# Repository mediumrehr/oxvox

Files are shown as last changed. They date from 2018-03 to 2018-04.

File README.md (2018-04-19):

# Ox Vox

The Ox Vox is a badge add-on created for the DEF CON 25 503 party and BSides PDX 2018 badges. The Ox Vox replaces the two joysticks on the badge with eight buttons and amplified speaker output.

## How To

### Connecting

Connecting the Ox Vox requires removing the joysticks from the badge. The pinouts are different for the DC25 Badge vs the BSides badge, so a few defines need to be changed depending on which badge you are modifying. Each joysticks uses five GPIOs, which allows for eight button inputs (a full octave), audio out, and an amplifier enable (see [Addition](#additions)).

Below shows how to connect the Ox Vox depending on which badge you're modifying.

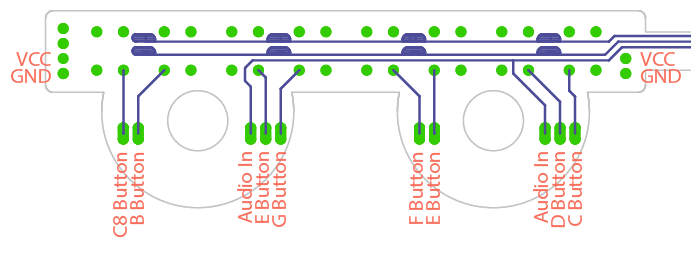
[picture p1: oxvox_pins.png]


#### DEF CON 25 503 Party Badge

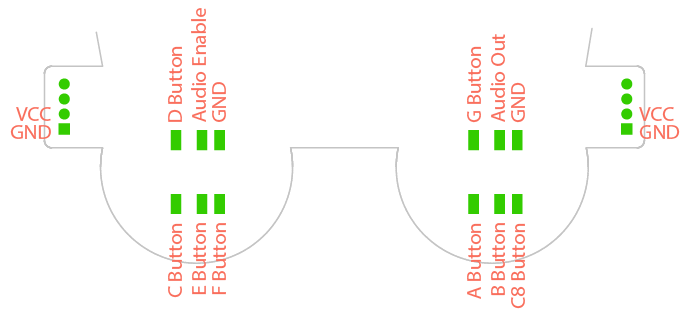
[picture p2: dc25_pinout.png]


#### BSides PDX Badge

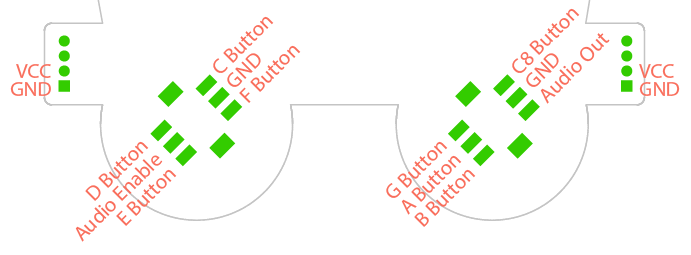
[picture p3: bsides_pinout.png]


### Programming

There are a few methods for programming the BMD-300 (NRF52832) SoC with the Ox Vox firmware via SWD. For this this project, I've been using the [BMD-300 Eval Kit](https://www.digikey.com/product-detail/en/rigado-inc/BMD-300-EVAL/1604-1007-ND/5958042) as a Segger J-Link Debugger as outlined in [this article](https://rigado.zendesk.com/hc/en-us/articles/223486428-How-are-the-BMD-200-and-BMD-300-Series-modules-programmed-). There are many cheap (<$10) J-Link-OB devices available that will likely work just as well, or you can probably use any other SWD device you have laying around.

In order to program the board, you need to break out the SWD interface. This requires soldering four male header pins to the pads shown below (directly below the i2c screen header). Looking at the badge from the back, the pins are SWCLK, SWDIO, 3v3, and GND.

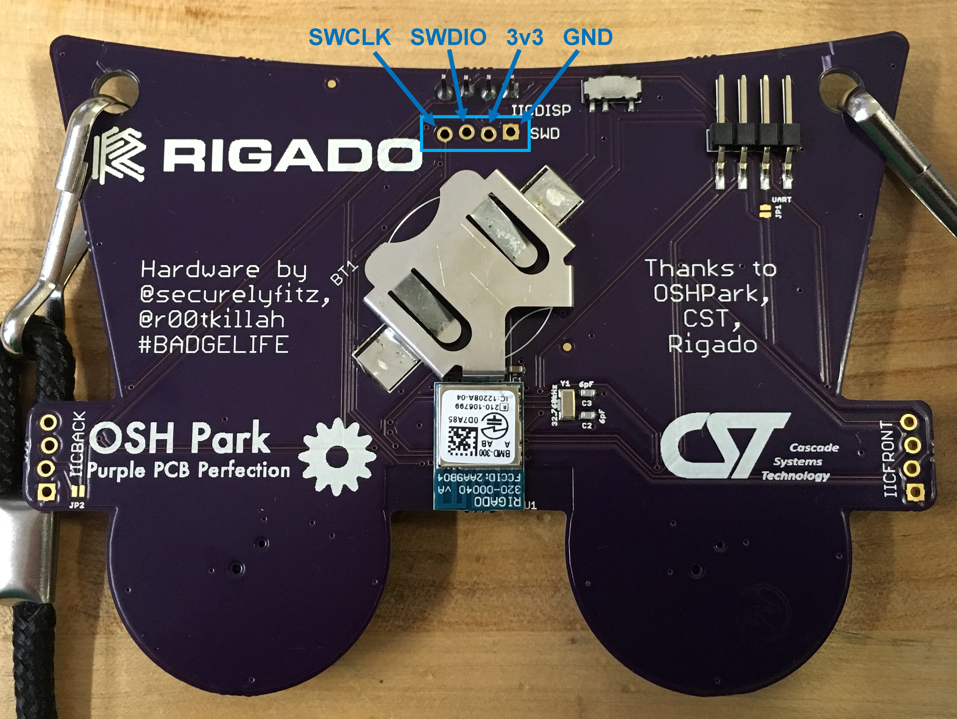
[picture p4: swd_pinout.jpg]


If you're using a J-Link interface, the badge should show mount to your OS when you plug it into your computer. You can then drop the appropriate (DC25 vs BSides) compiled hex file into the mounted folder and the NRF52 will take it from there.

If you want to build from source, follow [this guide](https://www.rigado.com/bmd-300-series-getting-started-guide/?wpdmdl=1810) (starting on page 9) for setting up Keil uVision, the nRF5 SDK, and Segger J-Link. Instead of downloading nRF5 SDK v12, download [nRF5 SDK v13.0.0](https://developer.nordicsemi.com/nRF5_SDK/nRF5_SDK_v13.x.x/) (it's possible this code will work with newer SDKs, but I have not tested with them).

## Hardware

PCB files, designed in Eagle v7.7.0, are included in the Hardware folder. The design features eight momentary-push buttons, a basic smoothing and amplifier circuit, and a .8W speaker. The buttons form a full octave keyboard from C (261.6 Hz) to C (523.3 Hz). The BMD-300 outputs a PWM signal that is smoothed and amplified by the LM4861 amplifier.

## Firmware

To build the project, drop the oxvox foldering into examples->peripheral in the SDK and drop components into the root of the SDK (it fixes a bug in the bsp driver and adds the board definitions to the boards folder). Opening oxvox.uvprojx will open the project in uVision. From there you can build and load the hex file onto the board (either by grabbing the hex file in \_build/ and dropping it onto the mounted JLINK device or by using uVision's load feature). If you're using uVision to load the firmware, make sure it is configured to support whatever SWD programmer you are using; you can configure this under Project->Options for Target->Debug.

## Additions

The Ox Vox amplifier, in combination with the OLED display, were quickly draining fresh batteries, so as proposed by [Scanlime](https://twitter.com/scanlime), I added support in the firmware to connect the shutown pin of the LM4861 to pin xxx of the BMD-300. This allows the amplifier to be turned off when no audio is being played in order to save some power, and so it doesn't compete with the current draw when the display is drawing more white pixels in the default image. In order to do this, the shutdown lead (highlighted below) needs to be desoldered and lifted off the pad, then wired to the xxx pad on the Badge. The shutdown pin was originally connected to ground so the amplifier would remain on, therefore part of the trace is under the LM4861. The easiest way to break that connection is to lift the lead instead of disconnect the pad.

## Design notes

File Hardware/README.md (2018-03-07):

### OX VOX Hardware
Schematic and layout created using [Eagle 7.7.0](https://www.autodesk.com/products/eagle/overview)

The design features eight momentary-push buttons, a basic smoothing and amplifier circuit, and a 800mW speaker. The buttons form a full octave keyboard from C (261.6 Hz) to C (523.3 Hz). The BMD-300 outputs a PWM signal that is smoothed and amplified by the LM4861 amplifier.

This layout is slightly different from the DC25 and BSidesPDX layouts. It features the LM4861 shutdown pin broken out, as suggested by [Micah Scott](https://github.com/scanlime). By breaking out the shutdown pin and connecting it to the remaining available BMD-300 GPIO, the amplifier can be to shutdown when not in use in order to save power. Please see the connection section for how to connect this, or connect it to ground to keep the amplifier always on.

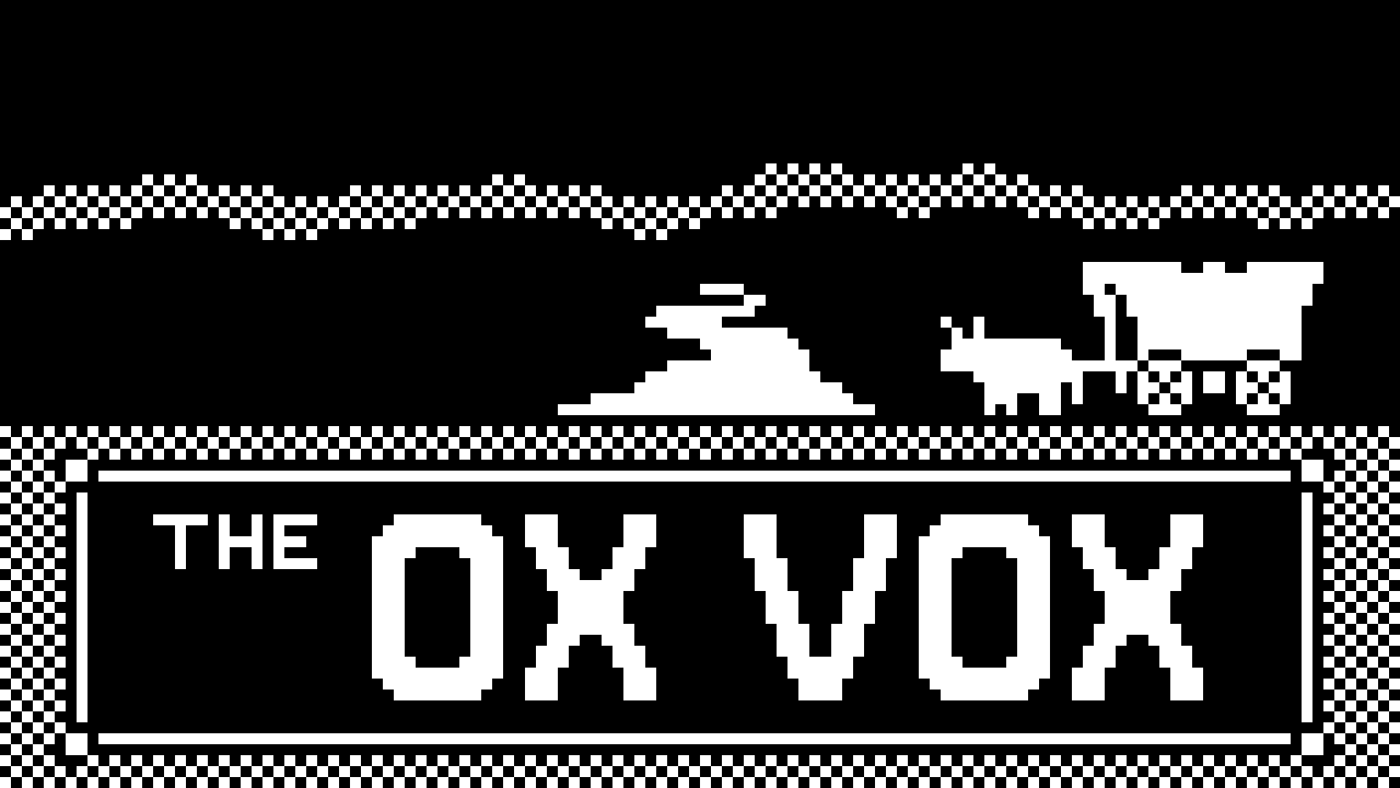
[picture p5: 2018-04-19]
Extras/oxvox_large.png

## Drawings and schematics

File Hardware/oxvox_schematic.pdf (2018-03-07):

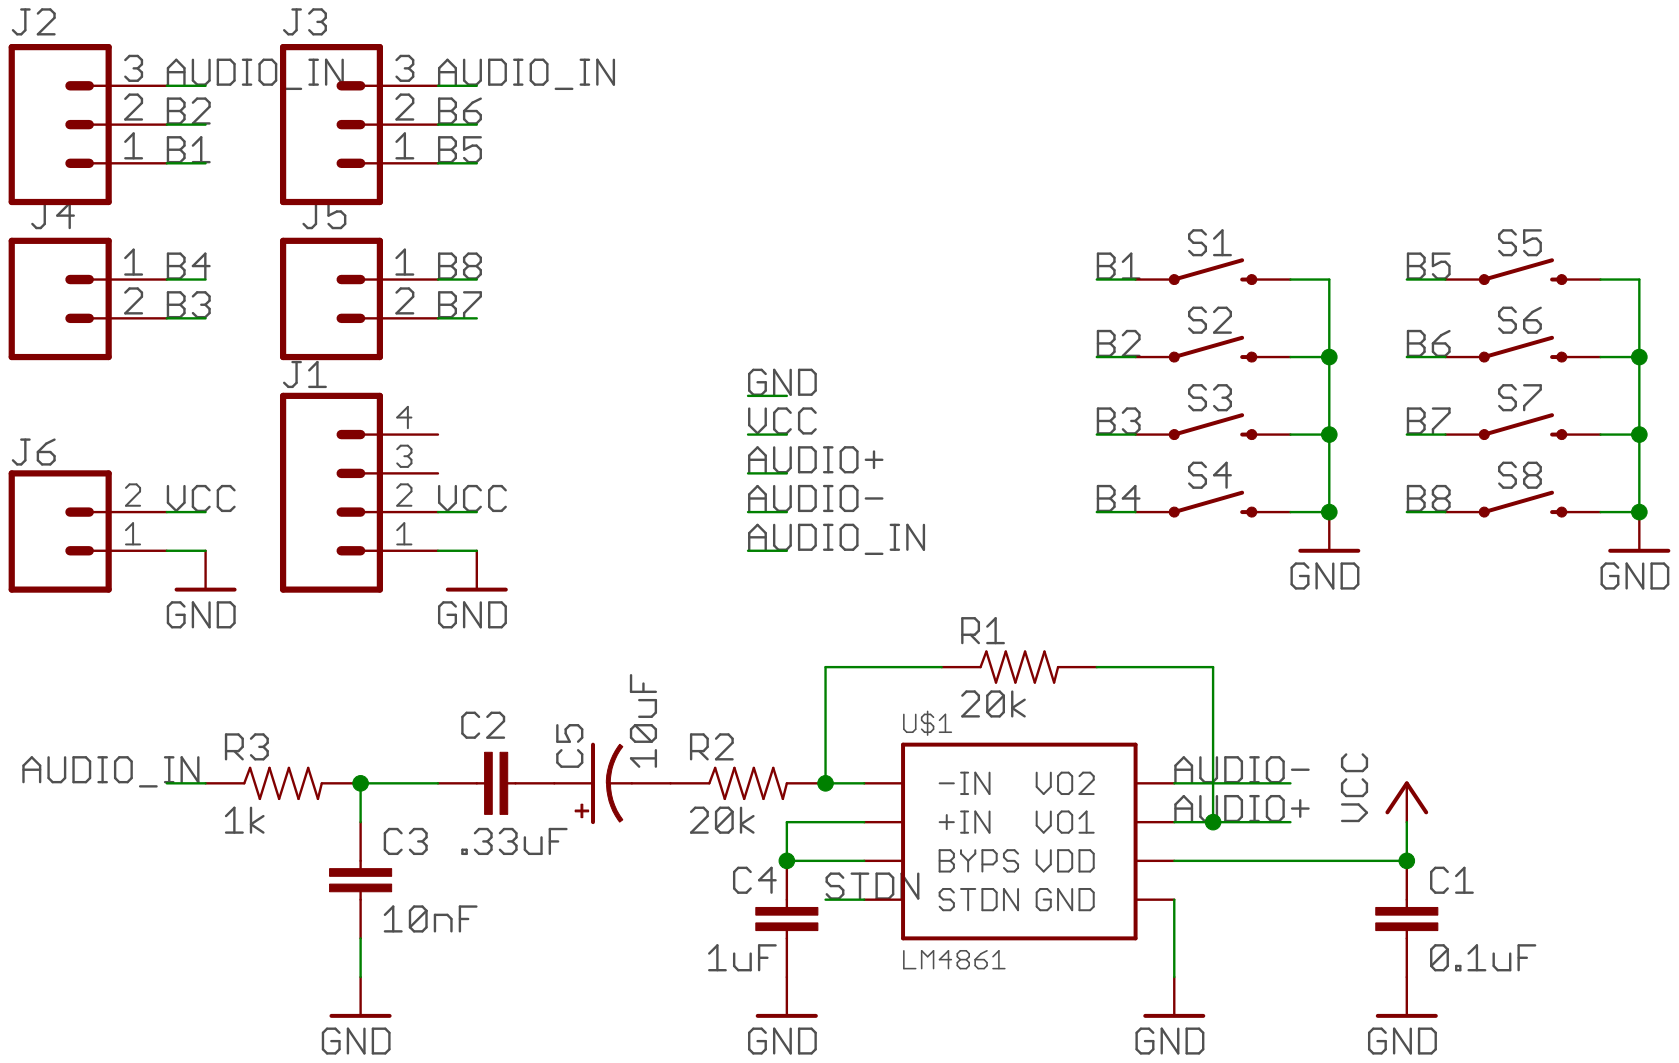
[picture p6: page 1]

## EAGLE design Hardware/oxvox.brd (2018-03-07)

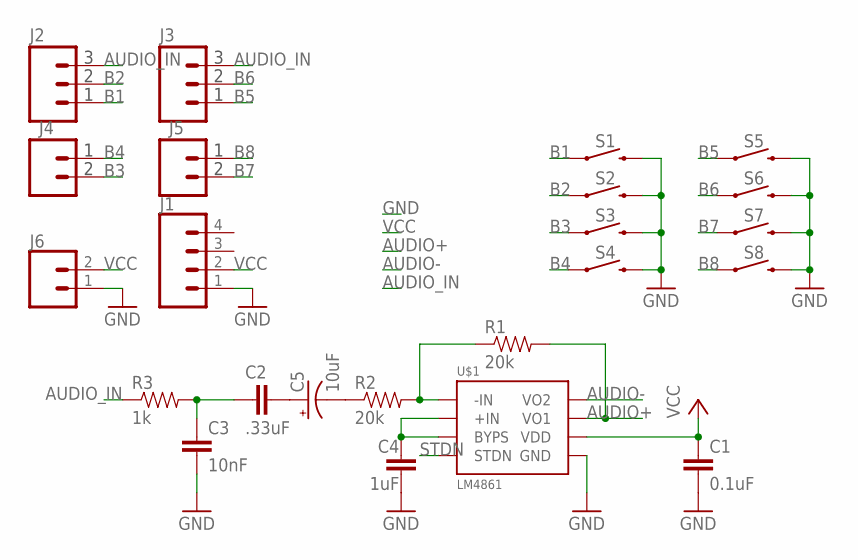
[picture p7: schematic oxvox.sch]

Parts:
C1: 0.1uF; 0603-CAP
C2: .33uF; 0603-CAP
C3: 10nF; 0603-CAP
C4: 1uF; 0603-CAP
C5: 10uF; RADIAL_SMT_4MM
J1: CONN_04; 1X04
J2, J3: M03-PTH_LONG_NO_SILK_BOT; M03_LONG_NO_SILK_BOTTOM
J4, J5: M02-PTH_LONG_NO_SILK_BOT; M02_LONG_NO_SILK_BOTTOM
J6: CONN_02; 1X02
R1, R2: 20k; 0805
R3: 1k; 0603-RES
S1, S2, S3, S4, S5, S6, S7, S8: MOMENTARY-SWITCH-SPST-PTH-6.0MM-KIT-ALL2; TACTILE_SWITCH_PTH_6.0MM_KIT_NOSILK
U$1: LM4861; 8-SOIC

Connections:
AUDIO+: R1.2, U$1.P$5 (VO1)
AUDIO-: U$1.P$8 (VO2)
AUDIO_IN: J2.P$3, J3.P$3, R3.1
B1: J2.P$1, S1.1, S1.2 (1)
B2: J2.P$2, S2.1, S2.2 (1)
B3: J4.P$2, S3.1, S3.2 (1)
B4: J4.P$1, S4.1, S4.2 (1)
B5: J3.P$1, S5.1, S5.2 (1)
B6: J3.P$2, S6.1, S6.2 (1)
B7: J5.P$2, S7.1, S7.2 (1)
B8: J5.P$1, S8.1, S8.2 (1)
GND: C1.2, C3.2, C4.2, J1.1, J6.1, S1.3 (2), S1.4 (2), S2.3 (2), S2.4 (2), S3.3 (2), S3.4 (2), S4.3 (2), S4.4 (2), S5.3 (2), S5.4 (2), S6.3 (2), S6.4 (2), S7.3 (2), S7.4 (2), S8.3 (2), S8.4 (2), U$1.P$7 (GND)
unnamed: R1.1, R2.2, U$1.P$4 (-IN)
unnamed: C2.2, C3.1, R3.2
unnamed: C5.P$2 (-), R2.1
unnamed: C4.1, U$1.P$2 (BYPS), U$1.P$3 (+IN)
unnamed: C2.1, C5.P$1 (+)
STDN: U$1.P$1 (STDN)
VCC: C1.1, J1.2, J6.2, U$1.P$6 (VDD)

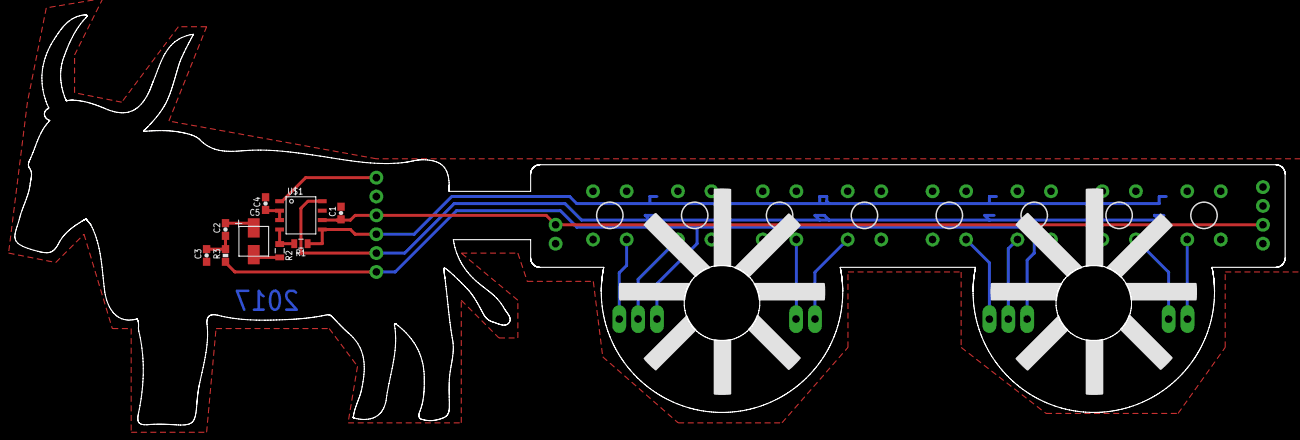
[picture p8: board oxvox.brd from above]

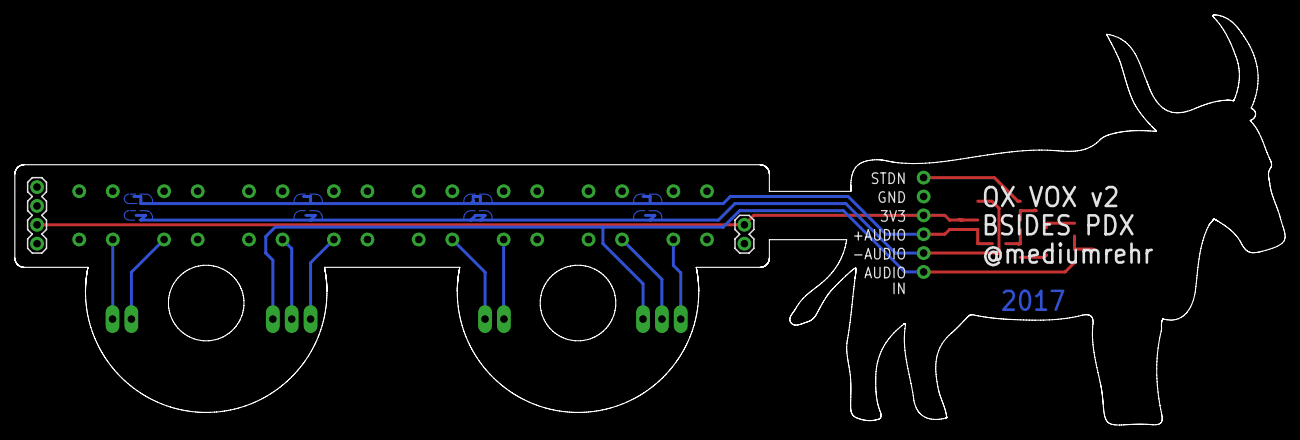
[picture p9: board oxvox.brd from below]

Board: 2 copper layers, 171.1 x 55.2 mm, 23 parts (6 on the bottom side), 17 nets.

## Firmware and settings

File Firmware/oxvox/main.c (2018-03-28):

/*
 * OX VOX v1.0
 * Rob Rehr (@mediumrehr)
 * March 28, 2018
 */

#include <stdio.h>
#include <string.h>
#include "nrf_drv_pwm.h"
#include "nrf_drv_twi.h"
#include "nrf_drv_timer.h"
#include "nrf_drv_clock.h"
#include "app_util_platform.h"
#include "app_error.h"
#include "boards.h"
#include "bsp.h"
#include "app_timer.h"
#include "nrf_gpio.h"
#include "nrf_gpiote.h"
#include "nrf_delay.h"
#include "oxvox.h"
#include "tables.h"
#include "screens.h"

/* PWM instance */
static nrf_drv_pwm_t m_pwm = NRF_DRV_PWM_INSTANCE(0);
/* Timer instance */
const nrf_drv_timer_t WAVETABLE_LOOKUP_TIMER = NRF_DRV_TIMER_INSTANCE(1);
/* TWI instance */
static const nrf_drv_twi_t m_twi = NRF_DRV_TWI_INSTANCE(TWI_INSTANCE_ID);

/* note to play */
// 1:C (261.6 Hz)
// 2:D (293.7 Hz)
// 3:E (329.6 Hz)
// 4:F (349.2 Hz)
// 5:G (392.0 Hz)
// 6:A (440.0 Hz)
// 7:B (493.4 Hz)
// 8:C (523.3 Hz)
static volatile uint8_t note = 0; // start silent
#ifdef _50KHZ_
    const uint8_t note_array_size[8] = {191, 170, 152, 143, 128, 114, 101, 96}; // 50kHz
#else
    const uint8_t note_array_size[8] = {76, 68, 60, 56, 52, 44, 40, 36}; // 20kHz
#endif

/* indicates if operation on TWI has ended */
static volatile bool m_xfer_done = false;

static volatile uint16_t tableIndex = 0;

/* set up PWM */
static nrf_pwm_values_individual_t m_pwm_seq_values;
static nrf_pwm_sequence_t const    m_pwm_seq = {
    .values.p_individual = &m_pwm_seq_values,
    .length              = NRF_PWM_VALUES_LENGTH(m_pwm_seq_values),
    .repeats             = 0,
    .end_delay           = 0
};

static void pwm_init(void) {
    nrf_drv_pwm_config_t const m_pwm_config = {
        .output_pins = {
            AUDIO_OUT_PIN | NRF_DRV_PWM_PIN_INVERTED, // channel 0
            NRF_DRV_PWM_PIN_NOT_USED, // channel 1
            NRF_DRV_PWM_PIN_NOT_USED, // channel 2
            NRF_DRV_PWM_PIN_NOT_USED  // channel 3
        },
        .irq_priority = APP_IRQ_PRIORITY_LOW,
        .base_clock   = NRF_PWM_CLK_16MHz,
        .count_mode   = NRF_PWM_MODE_UP,
        .top_value    = 255,
        .load_mode    = NRF_PWM_LOAD_INDIVIDUAL,
        .step_mode    = NRF_PWM_STEP_AUTO
    };
    APP_ERROR_CHECK(nrf_drv_pwm_init(&m_pwm, &m_pwm_config, NULL));

    m_pwm_seq_values.channel_0 = 0;
    m_pwm_seq_values.channel_1 = 0;
    m_pwm_seq_values.channel_2 = 0;
    m_pwm_seq_values.channel_3 = 0;

    (void)nrf_drv_pwm_simple_playback(&m_pwm, &m_pwm_seq, 1, NRF_DRV_PWM_FLAG_LOOP);
}

static void wavetable_lookup_timer_handler(nrf_timer_event_t event_type, void* p_context) {
    uint8_t channel = 0; // only using the first pwm channel
    uint16_t * p_channels = (uint16_t *)&m_pwm_seq_values;
    
    if (note == 0) {
        return;
    }
    
    if (tableIndex < note_array_size[note-1]) {
        tableIndex++;
    } else {
        tableIndex = 0;
    }
    
    // set the duty cycle for pwm from wavetable 
    switch(note) {
        case 1: // C
            #ifdef _50KHZ_
                p_channels[channel] = SinTableC_50k[tableIndex];
            #else
                p_channels[channel] = SinTableC8_20k[tableIndex];
            #endif
            break;
        
        case 2: // D
            #ifdef _50KHZ_
                p_channels[channel] = SinTableD_50k[tableIndex];
            #else
                p_channels[channel] = SinTableC8_20k[tableIndex];
            #endif
            break;
        
        case 3: // E
            #ifdef _50KHZ_
                p_channels[channel] = SinTableE_50k[tableIndex];
            #else
                p_channels[channel] = SinTableC8_20k[tableIndex];
            #endif
            break;
        
        case 4: // F
            #ifdef _50KHZ_
                p_channels[channel] = SinTableF_50k[tableIndex];
            #else
                p_channels[channel] = SinTableC8_20k[tableIndex];
            #endif
            break;
        
        case 5: // G
            #ifdef _50KHZ_
                p_channels[channel] = SinTableG_50k[tableIndex];
            #else
                p_channels[channel] = SinTableC8_20k[tableIndex];
            #endif
            break;
        
        case 6: // A
            #ifdef _50KHZ_
                p_channels[channel] = SinTableA_50k[tableIndex];
            #else
                p_channels[channel] = SinTableC8_20k[tableIndex];
            #endif
            break;
        
        case 7: // B
            #ifdef _50KHZ_
                p_channels[channel] = SinTableB_50k[tableIndex];
            #else
                p_channels[channel] = SinTableC8_20k[tableIndex];
            #endif
            break;
        
        case 8: // C
            #ifdef _50KHZ_
                p_channels[channel] = SinTableC8_50k[tableIndex];
            #else
                p_channels[channel] = SinTableC8_20k[tableIndex];
            #endif
            break;
        
        default:
            break;
    }
}

static void init_bsp(void) {
    APP_ERROR_CHECK(nrf_drv_clock_init());
    nrf_drv_clock_lfclk_request(NULL);

    APP_ERROR_CHECK(app_timer_init());
        APP_ERROR_CHECK(bsp_init(BSP_INIT_BUTTONS, bsp_evt_handler));
    APP_ERROR_CHECK(bsp_buttons_enable());
}

static void bsp_evt_handler(bsp_event_t evt) {
    switch (evt) {
        // Button 1 - play note 1
        case BSP_EVENT_KEY_0:
            if (bsp_button_is_pressed(0)) {
                display(1); // show C screen
                nrf_gpio_pin_clear(AUDIO_ENABLE_PIN); // enable audio out
                note = 1;
            } else {
                if (note == 1) {
                    display(0); // show main screen
                    nrf_gpio_pin_set(AUDIO_ENABLE_PIN); // disable audio out
                    note = 0;
                }
            }
            break;
                
        // Button 2 - play note 2
        case BSP_EVENT_KEY_1:
            if (bsp_button_is_pressed(1)) {
                display(2); // show D screen
                nrf_gpio_pin_clear(AUDIO_ENABLE_PIN); // enable audio out
                note = 2;
            } else {
                if (note == 2) {
                    display(0); // show main screen
                    nrf_gpio_pin_set(AUDIO_ENABLE_PIN); // disable audio out
                    note = 0;
                }
            }
            break;
                        
        // Button 3 - play note 3
        case BSP_EVENT_KEY_2:
            if (bsp_button_is_pressed(2)) {
                display(3); // show E screen
                nrf_gpio_pin_clear(AUDIO_ENABLE_PIN); // enable audio out
                note = 3;
            } else {
                if (note == 3) {
                    display(0); // show main screen
                    nrf_gpio_pin_set(AUDIO_ENABLE_PIN); // disable audio out
                    note = 0;
                }
            }
            break;
                
        // Button 4 - play note 4
        case BSP_EVENT_KEY_3:
            if (bsp_button_is_pressed(3)) {
                display(4); // show F screen
                nrf_gpio_pin_clear(AUDIO_ENABLE_PIN); // enable audio out
                note = 4;
            } else {
                if (note == 4) {
                    display(0); // show main screen
                    nrf_gpio_pin_set(AUDIO_ENABLE_PIN); // disable audio out
                    note = 0;
                }
            }
            break;
                
        // Button 5 - play note 5
        case BSP_EVENT_KEY_4:
            if (bsp_button_is_pressed(4)) {
                display(5); // show G screen
                nrf_gpio_pin_clear(AUDIO_ENABLE_PIN); // enable audio out
                note = 5;
            } else {
                if (note == 5) {
                    display(0); // show main screen
                    nrf_gpio_pin_set(AUDIO_ENABLE_PIN); // disable audio out
                    note = 0;
                }
            }
            break;
                
        // Button 6 - play note 6
        case BSP_EVENT_KEY_5:
            if (bsp_button_is_pressed(5)) {
                display(AUDIO_ENABLE_PIN); // show A screen
                nrf_gpio_pin_clear(AUDIO_ENABLE_PIN); // enable audio out
                note = 6;
            } else {
                if (note == 6) {
                    display(0); // show main screen
                    nrf_gpio_pin_set(AUDIO_ENABLE_PIN); // disable audio out
                    note = 0;
                }
            }
            break;
                
        // Button 7 - play note 7
        case BSP_EVENT_KEY_6:
            if (bsp_button_is_pressed(AUDIO_ENABLE_PIN)) {
                display(7); // show B screen
                nrf_gpio_pin_clear(AUDIO_ENABLE_PIN); // enable audio out
                note = 7;
            } else {
                if (note == 7) {
                    display(0); // show main screen
                    nrf_gpio_pin_set(AUDIO_ENABLE_PIN); // disable audio out
                    note = 0;
                }
            }
            break;
                
        // Button 8 - play note 8
        case BSP_EVENT_KEY_7:
            if (bsp_button_is_pressed(7)) {
                display(1); // show C screen
                nrf_gpio_pin_clear(AUDIO_ENABLE_PIN); // enable audio out
                note = 8;
            } else {
                if (note == 8) {
                    display(0); // show main screen
                    nrf_gpio_pin_set(AUDIO_ENABLE_PIN); // disable audio out
                    note = 0;
                }
            }
            break;

        default:
            display(0); // show main screen
            nrf_gpio_pin_set(AUDIO_ENABLE_PIN); // disable audio out
            note = 0;
            break;
    }
}

static void twi_init(void) {
    const nrf_drv_twi_config_t twi_config = {
       .scl                = OXVOX_SCL_PIN,
       .sda                = OXVOX_SDA_PIN,
       .frequency          = NRF_TWI_FREQ_400K,
       .interrupt_priority = APP_IRQ_PRIORITY_HIGH,
       .clear_bus_init     = false
    };

    APP_ERROR_CHECK(nrf_drv_twi_init(&m_twi, &twi_config, twi_handler, NULL));

    nrf_drv_twi_enable(&m_twi);
}

static void twi_handler(nrf_drv_twi_evt_t const* p_event, void* p_context) {
    switch (p_event->type) {
        case NRF_DRV_TWI_EVT_DONE:
            if (p_event->xfer_desc.type == NRF_DRV_TWI_XFER_RX) {
//                data_handler(m_sample);
            }
            m_xfer_done = true;
            break;
        default:
            break;
    }
}

static void init_ssd1306(void) {   
    // Init sequence
    ssd1306_command(SSD1306_DISPLAYOFF);                    // 0xAE
    ssd1306_command(SSD1306_SETDISPLAYCLOCKDIV);            // 0xD5
    ssd1306_command(0x80U);                                 // the suggested ratio 0x80

    ssd1306_command(SSD1306_SETMULTIPLEX);                  // 0xA8
    ssd1306_command(SSD1306_LCDHEIGHT - 1);                 // 0x3F (64)

    ssd1306_command(SSD1306_SETDISPLAYOFFSET);              // 0xD3
    ssd1306_command(0x0U);                                  // no offset
    ssd1306_command(SSD1306_SETSTARTLINE | 0x0);            // line #0
    ssd1306_command(SSD1306_CHARGEPUMP);                    // 0x8D
    
    ssd1306_command(0x14U);                                 // we'll generate the high voltage from the 3.3v line internally! (neat!)
    
    ssd1306_command(SSD1306_MEMORYMODE);                    // 0x20
    ssd1306_command(0x00U);                                 // 0x0 act like ks0108
    ssd1306_command(SSD1306_SEGREMAP | 0x1U);
    ssd1306_command(SSD1306_COMSCANDEC);
  
    // for 128x64
    ssd1306_command(SSD1306_SETCOMPINS);                    // 0xDA
    ssd1306_command(0x12U);
    ssd1306_command(SSD1306_SETCONTRAST);                   // 0x81
    ssd1306_command(0xCFU);
    
    ssd1306_command(SSD1306_SETPRECHARGE);                  // 0xd9
    
    ssd1306_command(0xF1U);                                 // we'll generate the high voltage from the 3.3v line internally! (neat!)
    
    ssd1306_command(SSD1306_SETVCOMDETECT);                 // 0xDB
    ssd1306_command(0x40U);
    ssd1306_command(SSD1306_DISPLAYALLON_RESUME);           // 0xA4
    ssd1306_command(SSD1306_NORMALDISPLAY);                 // 0xA6

    ssd1306_command(SSD1306_DEACTIVATE_SCROLL);

    ssd1306_command(SSD1306_DISPLAYON);//--turn on oled panel
}

static void ssd1306_command(uint8_t command) {
    m_xfer_done = false;
    
    uint8_t control = 0x00U;   // Co = 0, D/C = 0
    uint8_t reg[2] = {control, command};
    APP_ERROR_CHECK(nrf_drv_twi_tx(&m_twi, SSD1306_ADDR, reg, sizeof(reg), false));

    while (m_xfer_done == false);
}

static void display(uint8_t screen) {
    #ifdef _SHOW_DISPLAY_
        ssd1306_command(SSD1306_COLUMNADDR);
        ssd1306_command(0); // Column start address (0 = reset)
        ssd1306_command(SSD1306_LCDWIDTH-1); // Column end address (127 = reset)

        ssd1306_command(SSD1306_PAGEADDR);
        ssd1306_command(0); // Page start address (0 = reset)
        ssd1306_command(7); // Page end address
        
        for (uint16_t i=0; i<(SSD1306_LCDWIDTH*SSD1306_LCDHEIGHT/8); i++) {
            m_xfer_done = false;
            
            // send a bunch of data in one transmission
            uint8_t regVal1 = 0x40;
            uint8_t reg[17] = {regVal1, 0, 0, 0, 0, 0, 0, 0, 0, 0, 0, 0, 0, 0, 0, 0, 0};
            for (uint8_t x=0; x<16; x++) {
                if (screen == 0) { // OX VOX screen
                    reg[x+1] = buffer[i];
                } else if (screen == 1) { // C screen
                    reg[x+1] = c_buffer[i];
                } else if (screen == 2) { // D screen
                    reg[x+1] = d_buffer[i];
                } else if (screen == 3) { // E screen
                    reg[x+1] = e_buffer[i];
                } else if (screen == 4) { // F screen
                    reg[x+1] = f_buffer[i];
                } else if (screen == 5) { // G screen
                    reg[x+1] = g_buffer[i];
                } else if (screen == 6) { // A screen
                    reg[x+1] = a_buffer[i];
                } else if (screen == 7) { // B screen
                    reg[x+1] = b_buffer[i];
                }
                i++;
            }
            i--;
            
            APP_ERROR_CHECK(nrf_drv_twi_tx(&m_twi, SSD1306_ADDR, reg, 17, false));
            while (m_xfer_done == false);
        }
    #endif
}

int main(void) {    
    uint32_t time_ticks;
    uint32_t err_code = NRF_SUCCESS;

    init_bsp();
    
    // audio output pin
    nrf_gpio_cfg_output(AUDIO_OUT_PIN);
    nrf_gpio_pin_clear(AUDIO_OUT_PIN); // start with low
    
    // amlifier enable pin
    nrf_gpio_cfg_output(AUDIO_ENABLE_PIN);
    nrf_gpio_pin_set(AUDIO_ENABLE_PIN); // disable audio out
    
    //Configure WAVETABLE_LOOKUP_TIMER for updating pwm value at sampling rate
    nrf_drv_timer_config_t wavetable_lookup_timer_cfg = NRF_DRV_TIMER_DEFAULT_CONFIG;
    err_code = nrf_drv_timer_init(&WAVETABLE_LOOKUP_TIMER, &wavetable_lookup_timer_cfg, wavetable_lookup_timer_handler);
    APP_ERROR_CHECK(err_code);

    // set time(in miliseconds) between consecutive compare events
    #ifdef _50KHZ_
        uint32_t time_us = 20; // 50kHz
    #else
        uint32_t time_us = 50; // 20kHz
    #endif

    time_ticks = nrf_drv_timer_us_to_ticks(&WAVETABLE_LOOKUP_TIMER, time_us);
    nrf_drv_timer_extended_compare(&WAVETABLE_LOOKUP_TIMER, NRF_TIMER_CC_CHANNEL0, time_ticks, NRF_TIMER_SHORT_COMPARE0_CLEAR_MASK, true);
    nrf_drv_timer_enable(&WAVETABLE_LOOKUP_TIMER);

    #ifdef _SHOW_DISPLAY_
        twi_init();
        init_ssd1306();
        display(0);
    #endif

    pwm_init();

    for (;;) {  
        // Wait for an event.
        do {
            __WFE();
        } while (m_xfer_done == false);

        // Clear the event register.
        __SEV();
        __WFE();
    }
}

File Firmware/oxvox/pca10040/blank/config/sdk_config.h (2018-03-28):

#ifndef SDK_CONFIG_H
#define SDK_CONFIG_H
// <<< Use Configuration Wizard in Context Menu >>>\n
#ifdef USE_APP_CONFIG
#include "app_config.h"
#endif
// <h> nRF_Drivers 

//==========================================================
// <e> CLOCK_ENABLED - nrf_drv_clock - CLOCK peripheral driver
//==========================================================
#ifndef CLOCK_ENABLED
#define CLOCK_ENABLED 1
#endif
#if  CLOCK_ENABLED
// <o> CLOCK_CONFIG_XTAL_FREQ  - HF XTAL Frequency
 
// <0=> Default (64 MHz) 

#ifndef CLOCK_CONFIG_XTAL_FREQ
#define CLOCK_CONFIG_XTAL_FREQ 0
#endif

// <o> CLOCK_CONFIG_LF_SRC  - LF Clock Source
 
// <0=> RC 
// <1=> XTAL 
// <2=> Synth 

#ifndef CLOCK_CONFIG_LF_SRC
#define CLOCK_CONFIG_LF_SRC 1
#endif

// <o> CLOCK_CONFIG_IRQ_PRIORITY  - Interrupt priority
 

// <i> Priorities 0,2 (nRF51) and 0,1,4,5 (nRF52) are reserved for SoftDevice
// <0=> 0 (highest) 
// <1=> 1 
// <2=> 2 
// <3=> 3 
// <4=> 4 
// <5=> 5 
// <6=> 6 
// <7=> 7 

#ifndef CLOCK_CONFIG_IRQ_PRIORITY
#define CLOCK_CONFIG_IRQ_PRIORITY 7
#endif

// <e> CLOCK_CONFIG_LOG_ENABLED - Enables logging in the module.
//==========================================================
#ifndef CLOCK_CONFIG_LOG_ENABLED
#define CLOCK_CONFIG_LOG_ENABLED 0
#endif
#if  CLOCK_CONFIG_LOG_ENABLED
// <o> CLOCK_CONFIG_LOG_LEVEL  - Default Severity level
 
// <0=> Off 
// <1=> Error 
// <2=> Warning 
// <3=> Info 
// <4=> Debug 

#ifndef CLOCK_CONFIG_LOG_LEVEL
#define CLOCK_CONFIG_LOG_LEVEL 3
#endif

// <o> CLOCK_CONFIG_INFO_COLOR  - ANSI escape code prefix.
 
// <0=> Default 
// <1=> Black 
// <2=> Red 
// <3=> Green 
// <4=> Yellow 
// <5=> Blue 
// <6=> Magenta 
// <7=> Cyan 
// <8=> White 

#ifndef CLOCK_CONFIG_INFO_COLOR
#define CLOCK_CONFIG_INFO_COLOR 0
#endif

// <o> CLOCK_CONFIG_DEBUG_COLOR  - ANSI escape code prefix.
 
// <0=> Default 
// <1=> Black 
// <2=> Red 
// <3=> Green 
// <4=> Yellow 
// <5=> Blue 
// <6=> Magenta 
// <7=> Cyan 
// <8=> White 

#ifndef CLOCK_CONFIG_DEBUG_COLOR
#define CLOCK_CONFIG_DEBUG_COLOR 0
#endif

#endif //CLOCK_CONFIG_LOG_ENABLED
// </e>

#endif //CLOCK_ENABLED
// </e>

// <e> GPIOTE_ENABLED - nrf_drv_gpiote - GPIOTE peripheral driver
//==========================================================
#ifndef GPIOTE_ENABLED
#define GPIOTE_ENABLED 1
#endif
#if  GPIOTE_ENABLED
// <o> GPIOTE_CONFIG_NUM_OF_LOW_POWER_EVENTS - Number of lower power input pins 
#ifndef GPIOTE_CONFIG_NUM_OF_LOW_POWER_EVENTS
#define GPIOTE_CONFIG_NUM_OF_LOW_POWER_EVENTS 8
#endif

// <o> GPIOTE_CONFIG_IRQ_PRIORITY  - Interrupt priority
 

// <i> Priorities 0,2 (nRF51) and 0,1,4,5 (nRF52) are reserved for SoftDevice
// <0=> 0 (highest) 
// <1=> 1 
// <2=> 2 
// <3=> 3 
// <4=> 4 
// <5=> 5 
// <6=> 6 
// <7=> 7 

#ifndef GPIOTE_CONFIG_IRQ_PRIORITY
#define GPIOTE_CONFIG_IRQ_PRIORITY 7
#endif

// <e> GPIOTE_CONFIG_LOG_ENABLED - Enables logging in the module.
//==========================================================
#ifndef GPIOTE_CONFIG_LOG_ENABLED
#define GPIOTE_CONFIG_LOG_ENABLED 0
#endif
#if  GPIOTE_CONFIG_LOG_ENABLED
// <o> GPIOTE_CONFIG_LOG_LEVEL  - Default Severity level
 
// <0=> Off 
// <1=> Error 
// <2=> Warning 
// <3=> Info 
// <4=> Debug 

#ifndef GPIOTE_CONFIG_LOG_LEVEL
#define GPIOTE_CONFIG_LOG_LEVEL 3
#endif

// <o> GPIOTE_CONFIG_INFO_COLOR  - ANSI escape code prefix.
 
// <0=> Default 
// <1=> Black 
// <2=> Red 
// <3=> Green 
// <4=> Yellow 
// <5=> Blue 
// <6=> Magenta 
// <7=> Cyan 
// <8=> White 

#ifndef GPIOTE_CONFIG_INFO_COLOR
#define GPIOTE_CONFIG_INFO_COLOR 0
#endif

// <o> GPIOTE_CONFIG_DEBUG_COLOR  - ANSI escape code prefix.
 
// <0=> Default 
// <1=> Black 
// <2=> Red 
// <3=> Green 
// <4=> Yellow 
// <5=> Blue 
// <6=> Magenta 
// <7=> Cyan 
// <8=> White 

#ifndef GPIOTE_CONFIG_DEBUG_COLOR
#define GPIOTE_CONFIG_DEBUG_COLOR 0
#endif

#endif //GPIOTE_CONFIG_LOG_ENABLED
// </e>

#endif //GPIOTE_ENABLED
// </e>

// <e> PERIPHERAL_RESOURCE_SHARING_ENABLED - nrf_drv_common - Peripheral drivers common module
//==========================================================
#ifndef PERIPHERAL_RESOURCE_SHARING_ENABLED
#define PERIPHERAL_RESOURCE_SHARING_ENABLED 0
#endif
#if  PERIPHERAL_RESOURCE_SHARING_ENABLED
// <e> COMMON_CONFIG_LOG_ENABLED - Enables logging in the module.
//==========================================================
#ifndef COMMON_CONFIG_LOG_ENABLED
#define COMMON_CONFIG_LOG_ENABLED 0
#endif
#if  COMMON_CONFIG_LOG_ENABLED
// <o> COMMON_CONFIG_LOG_LEVEL  - Default Severity level
 
// <0=> Off 
// <1=> Error 
// <2=> Warning 
// <3=> Info 
// <4=> Debug 

#ifndef COMMON_CONFIG_LOG_LEVEL
#define COMMON_CONFIG_LOG_LEVEL 3
#endif

// <o> COMMON_CONFIG_INFO_COLOR  - ANSI escape code prefix.
 
// <0=> Default 
// <1=> Black 
// <2=> Red 
// <3=> Green 
// <4=> Yellow 
// <5=> Blue 
// <6=> Magenta 
// <7=> Cyan 
// <8=> White 

#ifndef COMMON_CONFIG_INFO_COLOR
#define COMMON_CONFIG_INFO_COLOR 0
#endif

// <o> COMMON_CONFIG_DEBUG_COLOR  - ANSI escape code prefix.
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

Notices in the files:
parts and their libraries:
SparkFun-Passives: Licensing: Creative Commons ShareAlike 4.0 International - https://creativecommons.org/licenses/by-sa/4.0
